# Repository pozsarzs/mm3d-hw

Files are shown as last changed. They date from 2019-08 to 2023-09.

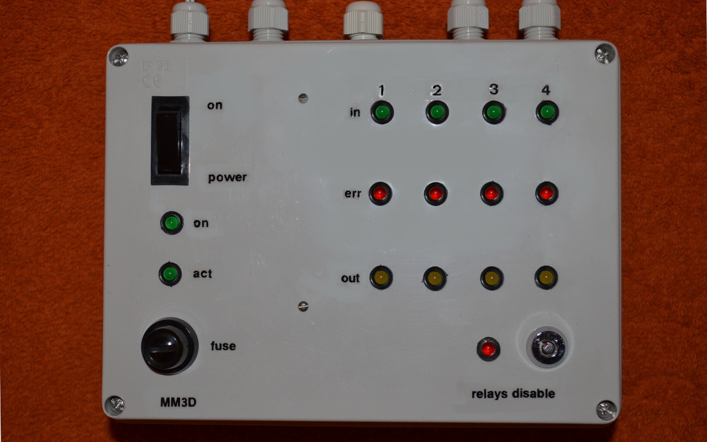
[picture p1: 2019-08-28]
pictures/mm3d.jpg

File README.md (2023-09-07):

**MM3D * Growing house controlling and remote monitoring device**  
Copyright (C) 2018-2020 Pozsár Zsolt <pozsarzs@gmail.com>  
Homepage: <http://www.pozsarzs.hu>  
GitHub: <https://github.com/pozsarzs/mm3d-hw>

**Documentation**

- version:             6.0
- language:            en, hu
- licence:             CC-BY-NC-4.0

**Hardware**

 - version:            v190203

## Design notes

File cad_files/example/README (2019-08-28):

Example of application
----------------------

Growing oyster mushroom in cellar
Cooperation with MM1A and MM2A analog controllers 

Inputs:
  in1:  (unused)
  in2:  water pressure (closed: good)
  in3:  growing hyphae/mushroom (closed: hyphae)
  in4:  (unused)

Error light:
  err1: bad relative humidity
  err2: bad water pressure
  err3: (unused)
  err4: bad temperature

Outputs:
  out1: humidifying (active in 5 s)
  out2: lighting
  out3: ventilation
  out4: heating

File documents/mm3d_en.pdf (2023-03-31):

## MM3D growing house controlling and monitoring unit

### Technical manual

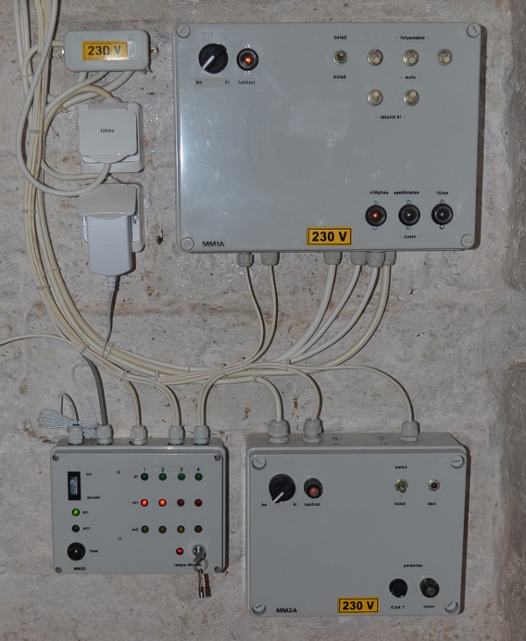
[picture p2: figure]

Hardware version: v190203
Software version: v0.8
User Manual version: v6.0
Issue date: 2022-03-13

## CC-BY-NC-4.0

(59/3)

Content

Titles: | MM3D growing house controlling and monitoring unit | Rev.: 190203 Pages: | 2/27
| Technical manual
Name: Pozsár Zsolt | Date: | 2022-03-13

## I. Hardware

Titles: | MM3D growing house controlling and monitoring unit | Rev.: 190203 Pages: | 3/27

The device is capable of measuring, controlling and monitoring the characteristics of a growing site.

### 1. Technical data

Supply voltage: | 5V DC (powered by 230 V AC/5 V DC adapter)
Supply current: | max. 2.5 A
Isolation class: | Class II.
Mechanical size: | 190 x 140 x 70 mm
IP protection: | IP 54
IK protection: | IK 03
Material of cover: | termoplaszt (ABS)
LAN: | Ethernet (RJ45)

Measured data:
value | range | resolution | accuration | note
temperature | -40...+80 °C | 0.1 °C | < ±0.5 °C | Length of sensor cable: max. 20 m
humidity | 0-100% RH | 0.1 % RH | ±2 % RH

Programmable in- and outputs:
sign | function | note
IN #1 | MMxA units in external control | TTL level inputs with pull-up resistor, theirs active state is „L”.
IN #2 | water pressure is good
IN #3 | mushroom/hyphae
IN #4 | MMxA units in automatic mode
OUT #1 | humidifying | NO/NC relay contact outputs. Load capacity: 250V 10A AC or 30V 10A DC. The operation of the relays can be switched off with a key switch, this status is indicated by a red LED.
OUT #2 | lighting
OUT #3 | ventilating
OUT #4 | heating

Programmable error lights:
sign | function | note
ERR #1 | bad humidity | Red LEDs on front panel.
ERR #2 | low water pressure
ERR #3 | control or sensor error
ERR #4 | bad temperature
Titles: | MM3D growing house controlling and monitoring unit | Rev.: 190203 Pages: | 4/27

### 2. Administration

Setting: | via SSH
Access data: | with web browser (via HTTP)

### 3. Description

The device is based on a Raspberry Pi 3 B + microcomputer with Raspbian operating system, which also includes software for operating the unit. No graphics system installed on it.

The device's four TTL-level inputs are equipped with pull-up resistors and have an active level of L. They can be used, for example, to check the position of air vents, doors and windows, check the functioning of the ventilation system (airflow sensor), the water pressure sensor, or the status of the motor or overcurrent protection devices with auxiliary contact.

The device has four relay contact outputs that are capable of switching to relatively high power (2.3 kW at 230V AC). The operation of the relays can be disabled by means of a front key switch; In all cases, external circuits must be provided with overcurrent protection.

There is no need to connect a keyboard or monitor to set up and operate the MM3D, and access to it is always done through SSH. Current status and measured data can be checked using a web browser.

### 4. Schematic and printed circuit drawings

The wiring diagram of the device is shown in Annex 1, PCB drawings are in Annex 3-7. You can download it as part of the complete documentation or in separate PS, PDF, SVG and KiCAD formats from the developer / manufacturer's website.

### 5. Terms of use

Hardware documentation can be modified and/or redistributed under the Creativ Commons 4.0 Attribution Non-Commercial (CC-BY-NC-4.0) License. You can read the full (English) text of the license online. (Refer to Chapter IV for references.)

Titles: | MM3D growing house controlling and monitoring unit | Rev.: 190203 Pages: | 5/27

### 6. Look of the device

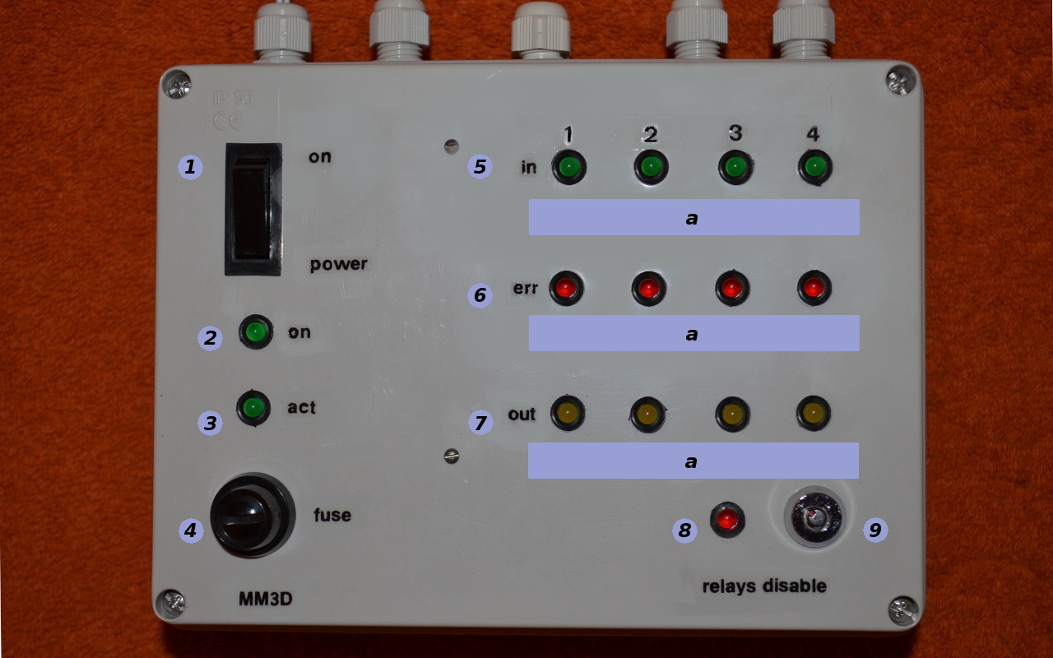
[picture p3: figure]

a) Manuals and connectors

1: supply voltage on/off switch 2: power on light (green LED)
3: ACT light (green LED)
4: fuse of supply voltage (2,5 A F)
5: IN #1-#4 input active status lights (green LED)
6: OUT #1-#4 output active status lights (yellow LED) 7: ERR #1-#4 error lights (red LED)
8: disable output relays light (red LED)
9: disable output relays switch

a: place for sticky labels

Titles: | MM3D growing house controlling and monitoring unit | Rev.: 190203 Pages: | 6/27

Figure 1: Front panel

b) Connector pinout

Input terminal (J1):
1: IN GND
2: IN #1
3: IN #2
4: IN #3
5: IN #4
6: -
7: -
8: S1 GND (external sensor GND) 9: S1 data (external sensor data) 10: S1 +5V (external sensor +5V) 11: +5 V in (power voltage input) 12: GND in (power voltage input)

Output terminal (J3):

1: NC1
2: COM1
3: NO1
4: NC2
5: COM2
6: NO2
7: NC3
8: COM3
9: NO3
10: NC4
11: COM4
12: NO4

Numbering on both connectors (terminal blocks) is in the installed position of device from top to bottom.

Titles: | MM3D growing house controlling and monitoring unit | Rev.: 190203 Pages: | 7/27

### 7. Downloadable documentation

The complete documentation of the hardware in the .tar.gz format compressed file can be downloaded from the manufacturer's website. (Refer to Chapter IV for references.)

Package's name: mm3d-hw-190203-6.0.tar.gz

Content:

mm3d-hw
│
├───cad_files | | KiCAD files
│ | ├───example | | | example of application
│ | │ | example_routing.pro | | | project file
│ | │ | example_routing.sch | | | schematic drawing
│ | │ | README | | | information
│ | │ | *.* | | | other files
│ | │
│ | └───mm3d | | | MM3D unit
│ | mm3d_base.pro | | base panel project file
│ | mm3d_base.kicad_pcb | | base printed circuit board
│ | mm3d_front.pro | | front panel project file
│ | mm3d_front.kicad_pcb | | front printed circuit board
│ | mm3d.pro | | schematic project file
│ | mm3d.sch | | schematic drawing
│ | *.* | | other files
│
├───documents | | documentation
│ | mm3d-hw_en.pdf | | Technical manual
│ | pcb_mm3d_base-comp.ps | | base panel component side
│ | pcb_mm3d_base-silk.ps | | base panel silkscreen
│ | pcb_mm3d_base-sold.ps | | base panel solder side
│ | pcb_mm3d_front-silk.ps | | front panel silkscreen
│ | pcb_mm3d_front-sold.ps | | front panel solder side
│ | sch_example.pdf | | example schematic drawing
│ | sch_mm3d.pdf | | MM3D schematic drawing
│
├───pictures | | pictures
│ | mm3d.jpg | | front panel
│ | pcb_mm3d_base-comp.svg | | base panel component side
│ | pcb_mm3d_base-silk.svg | | base panel silkscreen
│ | pcb_mm3d_base-sold.svg | | base panel solder side
│ | pcb_mm3d_front-silk.svg | | front panel silkscreen
│ | pcb_mm3d_front-sold.svg | | front panel solder side
│ | sch_example.svg | | example schematic drawing
│ | sch_mm3d.svg | | schematic drawing
│
├───LICENCE | terms of use
└───README.md | short description
Titles: | MM3D growing house controlling and monitoring unit | Rev.: 190203 Pages: | 8/27

## II. Software

Titles: | MM3D growing house controlling and monitoring unit | Rev.: 190203 Pages: | 9/27

### 1. General description

Operation of the device is provided by Python (control), Perl (data access) and Bash (utilities) scripts.

### 2. Prepare

Before installing the program, you must install Raspbian OS Lite on Raspberry Pi. Remember to change the default password for the user 'pi', configure the hostname and access to the local network. For easier remote access, use a permanent IP address or configure the IP address assignment on your router.

Prepare operation system:

pi@raspberry$ sudo apt-get update
pi@raspberry$ sudo apt-get upgrade
pi@raspberry$ sudo apt-get install git wget
pi@raspberry$ sudo echo "deb http://www.szerafingomba.hu/deb/ ./" >> /etc/apt/sources.list
pi@raspberry$ sudo wget -q -O - http://www.szerafingomba.hu/deb/KEY.gpg | apt-key add -
pi@raspberry$ sudo apt-get update
pi@raspberry$ mkdir $HOME/download

### 3. Download

Download from homepage:

pi@raspberry$ cd $HOME/download
pi@raspberry$ wget http://www.szerafingomba.hu/softwares/mm3d/mm3d-sw-0.8-armhf.tar.gz pi@raspberry$ tar -xzf mm3d-sw-0.8-armhf.tar.gz

Download new release from Github:

pi@raspberry$ cd $HOME/download
pi@raspberry$ git clone https://github.com/pozsarzs/mm3d-sw.git

### 4. Installation

pi@raspberry$ cd mm3d-sw
pi@raspberry$ ./prepare
pi@raspberry$ ./install

Install program from internet with package manager:

pi@raspberry$ sudo apt-get install mm3d-prepare pi@raspberry$ mm3d-prepare
pi@raspberry$ sudo apt-get install mm3d-sw mm3d-web mm3d-eec
Titles: | MM3D growing house controlling and monitoring unit | Rev.: 190203 Pages: | 10/27

The installed and created on runtime files (important files with info and target of symbolic links):

/
│
├───etc
│ | ├───cron.d
│ | │ | mm3d
│ | ├───init.d
│ | │ | mm3d.sh
│ | ├───rc0.d
│ | │ | K01mm3d.sh | » /etc/init.d/mm3d.sh
│ | ├───rc2.d
│ | │ | S01mm3d.sh | » /etc/init.d/mm3d.sh
│ | ├───rc3.d
│ | │ | S01mm3d.sh | » /etc/init.d/mm3d.sh
│ | │
│ | ├───rc4.d
│ | │ | S01mm3d.sh | » /etc/init.d/mm3d.sh
│ | ├───rc5.d
│ | │ | S01mm3d.sh | » /etc/init.d/mm3d.sh
│ | ├───rc6.d
│ | │ | K01mm3d.sh | » /etc/init.d/mm3d.sh
│ | ├───systemd
│ | │ | └───sytem
│ | │ | mm3d.service
│ | └───motd
├───usr
│ | ├───lib
│ | │ | | └───cgi
│ | │ | | | getdata.cgi
│ | │ | | | getenvirconf.cgi
│ | │ | | | getpage.cgi
│ | └───local
│ | | ├───bin
│ | | │ | | mm3d.py | daemon program
│ | │ | mm3d-creatediagrams | diagramok készítése
│ | │ | mm3d-editenvirconf | edit environment parameters
│ | │ | mm3d-editenvirconf.bin | edit environment parameters
│ | │ | mm3d-editmainconf | edit program configuration
│ | │ | mm3d-getsnapshots | kameraképek letöltése
│ | │ | mm3d-hwtest.py | hardver check
│ | │ | mm3d-maintainlog | log maintaining
│ | │ | mm3d-override | output manual control
│ | │ | mm3d-startdaemon | start daemon
│ | │ | mm3d-statusofdaemon | view status of daemon
│ | │ | mm3d-stopdaemon | stop daemon
│ | │ | mm3d-updatestartpage | update startpage
│ | │ | mm3d-viewlog | view log
│ | │ | mm3d-webpage | view own webpage
│ | ├───etc
│ | │ | └───mm3d
│ | │ | mm3d.ini | program configuration
│ | │ | envir.ini | environment parameters
│ | └───share
│ | | ├───doc
│ | | │ | └───mm3d
│ | | │ | AUTHORS | author
│ | | │ | ChangeLog | change log
│ | │ | control.txt | important variables
│ | │ | COPYING | licence
│ | │ | copyright | copyright information
│ | │ | gpioports.txt | GPIO port default pinout
Titles: | MM3D growing house controlling and monitoring unit | Rev.: 190203 Pages: | 11/27

│ | │ | INSTALL | installation instruction
│ | │ | README | description
│ | │ | VERSION | version
│ | ├───locale
│ | │ | └───??
│ | │ | mm3d.msg
│ | ├───man
│ | │ | └───man1 | manual pages
│ | │ | getdata.cgi.7.gz
│ | │ | getenvirconf.cgi.7.gz
│ | │ | getpage.cgi.7.gz
│ | │ | mm3d.py.8.gz
│ | │ | mm3d-creatediagrams.1.gz
│ | │ | mm3d-editenvirconf.1.gz
│ | │ | mm3d-editmainconf.1.gz
│ | │ | mm3d-getsnapshots.1.gz
│ | │ | mm3d-hwtest.py.1.gz
│ | │ | mm3d-maintainlog.1.gz
│ | │ | mm3d-override.1.gz
│ | │ | mm3d-startdaemon.1.gz
│ | │ | mm3d-statusofdaemon.1.gz
│ | │ | mm3d-stopdaemon.1.gz
│ | │ | mm3d-updatestartpage.1.gz
│ | │ | mm3d-viewlog.1.gz
│ | │ | mm3d-webpage.1.gz
│ | └───mm3d
│ | | footer_??.html
│ | | header_??.html
└───var
| ├───local
| │ | | ├───lib
| │ | | │ | | out1
| │ | | │ | | out2
| │ | | │ | | out3
| │ | | │ | | out4
| │ | | ├───lock
| │ | | │ | | mm3d.lock
| │ | | │
| │ | | └───log
| │ | | | mm3d.bak
| │ | | | mm3d.log
| │ | | | debug-*.log | | debug log
| ├───run
| │ | | mm3d.pid
| └───www
| | └───html
| | | ├───pics
│ | ants.jpg
│ | camera1.jpg
│ | camera2.jpg
│ | dark.png
│ | green.png
│ | humidity.png
│ | mm3d-creatediagrams.tmp
│ | red.png
│ | szerafin.ico
│ | temperature.png
│ | yellow.png
styles.css
index.html
szerafin.ico
Titles: | MM3D growing house controlling and monitoring unit | Rev.: 190203 Pages: | 12/27

It that is installed with the package manager is placed in the /usr directory instead of /usr/local.

### 3. Settings

Edit main settings:

mm3d@raspberry$ mm3d-editmainconf
The shellscript stops the service and opens the mm3d.ini file in the default editor. After saving the file, it refreshes the homepage and launches daemont. Content of configuration file:

; +----------------------------------------------------------------------------+
; | MM3D v0.6 * Growing house controlling and remote monitoring system | |
; | Copyright (C) 2018-2022 Pozsár Zsolt <pozsar.zsolt@szerafingomba.hu> | |
; | mm3d.ini | |
; | Main settings | |
; +----------------------------------------------------------------------------+

[user]
; User's data
usr_nam=User's name | ; user's name
usr_uid=00000000 | ; user's ID
usr_dt1=User's city | ; more data (eg. country)
usr_dt2=User's address | ; more data (eg. address)
usr_dt3=Growing house number | ; more data (eg. growing house)

[names]
; Name of error lights and ports
nam_err1=unnamed #1 | ; name of error lights
nam_err2=unnamed #2
nam_err3=unnamed #3
nam_err4=unnamed #4
nam_in1=unnamed #1 | ; name of inputs
nam_in2=unnamed #2
nam_in3=unnamed #3
nam_in4=unnamed #4
nam_out1=unnamed #1 | ; name of outputs
nam_out2=unnamed #2
nam_out3=unnamed #3
nam_out4=unnamed #4

[ports]
; GPIO port number of error lights and ports prt_act=24
prt_err1=14
prt_err2=15
prt_err3=18
prt_err4=23
prt_in1=2
prt_in2=3
prt_in3=4
prt_in4=17
prt_sens=11
prt_out1=27
prt_out2=22
prt_out3=10
prt_out4=9

[sensors]
; Type of temperature and humidity sensor ;sensor_type=AM2302
;sensor_type=DHT11
sensor_type=DHT22
Titles: | MM3D growing house controlling and monitoring unit | Rev.: 190203 Pages: | 13/27

[directories]
; Directories of program
dir_htm=/var/www/html/ | ; webserver's directory
dir_lck=/var/local/lock/ | ; lock file's directory
dir_log=/var/local/log/ | ; logfile's directory
dir_msg=/usr/local/share/locale/ | ; message files' directory
dir_shr=/usr/local/share/mm3d/ | ; other files' directory
dir_tmp=/var/tmp/ | ; place of temporary files
dir_var=/var/local/lib/mm3d/ | ; workfiles's directory
[openweathermap.org] | ;login data
api_key=00000000000000000000000000000000 base_url=http://api.openweathermap.org/data/2.5/weather?city_name=Tiszafoldvar
[ipcameras] | ; Show IP cameras' picture
cam_show=1
cam1_enable=0
cam1_jpglink=http://camera1-th01.lan/snapshot.cgi?user=username&pwd=password&count=0cam2_enable=0
cam2_jpglink=http://camera2-th01.lan/snapshot.cgi?user=username&pwd=password&count=0

[others]
; Language of webpage
lng=en
;lng=...
; Storing time of log
day_log=7
; Enable/disable verbose debug log
dbg_log=0
; Number of log lines on web interface
web_lines=30 | ; Showed log lines

Set growing environment parameters:

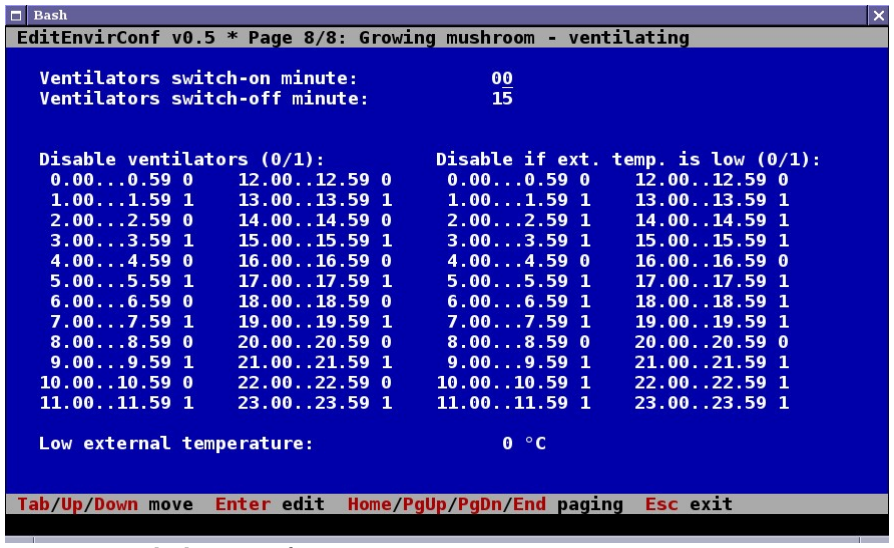
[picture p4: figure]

mm3d@raspberry$ mm3d-editenvirconf

Titles: | MM3D growing house controlling and monitoring unit | Rev.: 190203 Pages: | 14/27

Figure 2: mm3d-editenvirconf

The shell program starts the setup program and then resumes the service after saving and exiting.

### 6. Using the device

The device works automatically after installation and does not require human intervention. Checking and configuring your operation is only possible remotely via a network.

The device can be configured via SSH, the environmental characteristics can be set via SSH or with XMMEEC program. In the second case, a key-based login is required.

The set environment characteristic, the current status and the measured data can be checked with a web browser or MM3DRead program. Many data can be queried over HTTP without a browser. See getdata.cgi.7.gz manual page for details.

### 7. Terms of use

This program is free software: you can redistribute it and/or modify it under the terms of the European Union Public License 1.1 version.

This program is distributed in the hope that it will be useful, but WITHOUT ANY WARRANTY; without even the implied warranty of MERCHANTABILITY or FITNESS FOR A PARTICULAR PURPOSE.

You can read the full text of the license online. (Refer to Chapter IV for references.)

### 8. Downloadable software package

The package can be downloaded from the manufacturer's website in a .tar.gz compressed file. (Refer to Chapter IV for references.) Name of current package: mm3d-sw-0.8-armhf.tar.gz

Titles: | MM3D growing house controlling and monitoring unit | Rev.: 190203 Pages: | 15/27

Content of package:

mm3d-sw
│
├───binary | binary files
│
├───documents | documentation
│
├───manuals | manual pages
│
├───messages | translated webpage text
│
├───packaging | files for make deb packages
│
├───programs | programs (Python)
│
├───scripts | programs (Bash)
│
├───settings | settings
│
├───source | source code
│
├───webpage | | components of webpage
│
├───install | installer script
├───prepare | script for prepare OS
├───uninstall | uninstaller script
├───LICENCE | terms of use
└───README.md | short description
Titles: | MM3D growing house controlling and monitoring unit | Rev.: 190203 Pages: | 16/27

## III. Related links

Titles: | MM3D growing house controlling and monitoring unit | Rev.: 190203 Pages: | 17/27

### 1. Hardware

Full documentation | http://www.szerafingomba.hu/equipments/mm3d/mm3d-hw-190203-6.0.tar.gz
Github | https://github.com/pozsarzs/mm3d-hw.git
Technical manual | http://www.szerafingomba.hu/equipments/mm3d/technical-manual-190203-6.0-en.pdf

Schematic drawings:
Example (PDF) | http://www.szerafingomba.hu/equipments/mm3d/sch_mm3d-example.pdf
MM3D (PDF) | http://www.szerafingomba.hu/equipments/mm3d/sch_mm3d.pdf

Printed circuit boards:
MM3D base | http://www.szerafingomba.hu/equipments/mm3d/pcb_mm3d-1.zip
MM3D front | http://www.szerafingomba.hu/equipments/mm3d/pcb_mm3d-2.zip

### 2. Software

Software package | http://www.szerafingomba.hu/softwares/mm3d/mm3d-sw-0.8.1-armhf.tar.gz
Github | http://github.com/pozsarzs/mm3d-sw.git

### 3. Terms of use

CC-BY-NC-4.0 | https://creativecommons.org/licenses/by-nc/4.0/legalcode
CC-BY-NC-4.0 | https://creativecommons.org/licenses/by-nc/4.0/
EUPL v1.2 | https://eupl.eu/1.2/en/

### 4. Developer and manufacturer

Homepage | https://www.szerafingomba.hu
E-mail | info@szerafingomba.hu
Titles: | MM3D growing house controlling and monitoring unit | Rev.: 190203 Pages: | 18/27

## IV. Annexes

Titles: | MM3D growing house controlling and monitoring unit | Rev.: 190203 Pages: | 19/27

### 1. Schematic drawings

1. Schematic of MM3D
2. Example of application

### 2. Printed circuit boards

3. Base panel component side
4. Base panel solder side
5. Base panel silkscreen
6. Front panel component side
7. Front panel silkscreen
Titles: | MM3D growing house controlling and monitoring unit | Rev.: 190203 Pages: | 20/27

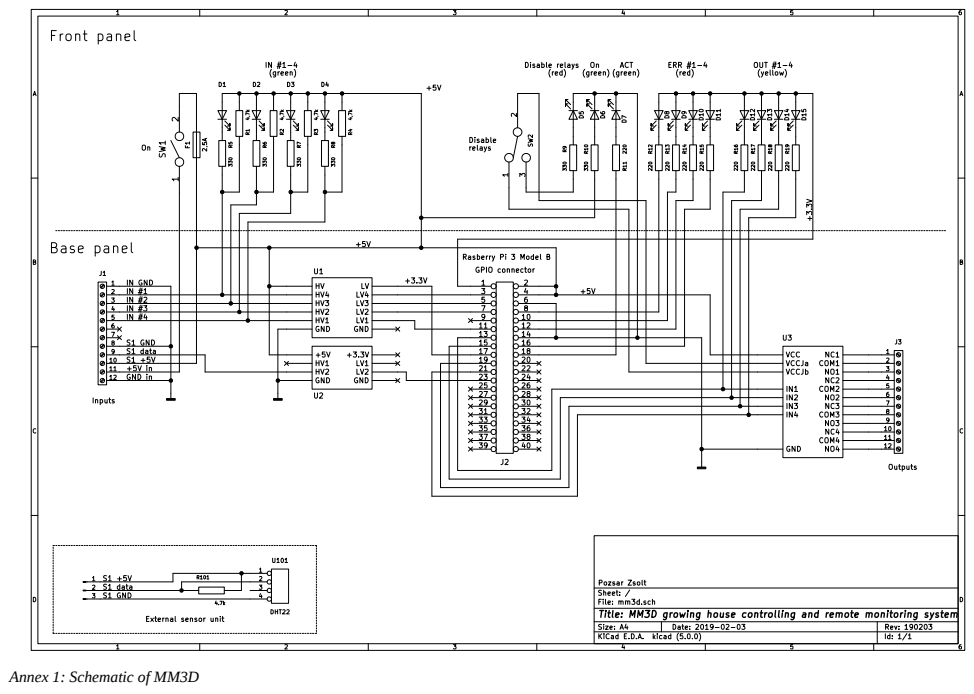
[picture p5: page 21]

Annex 1: Schematic of MM3D

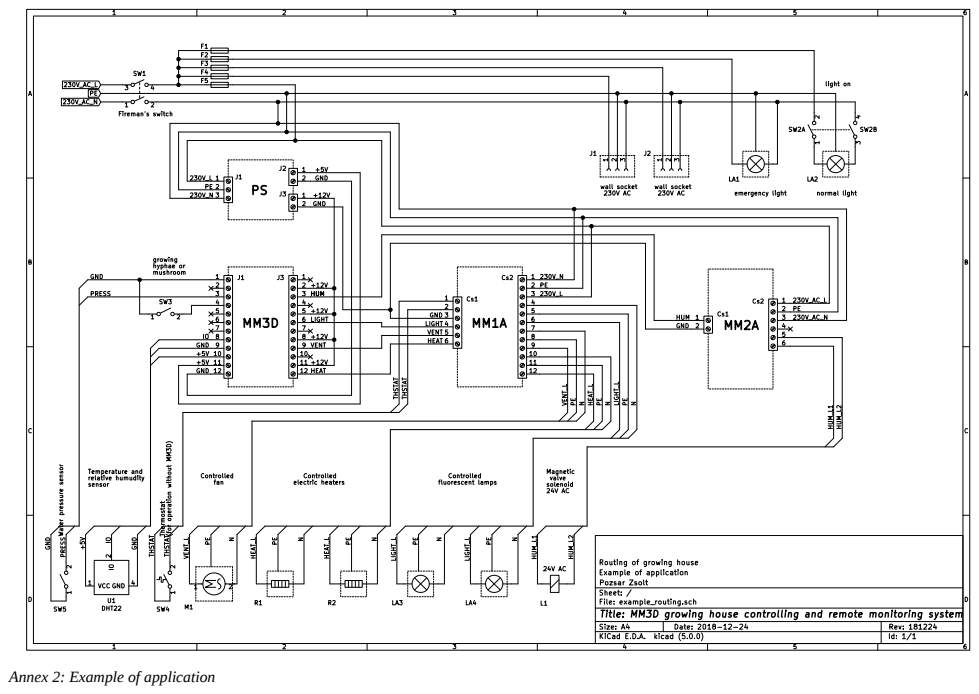
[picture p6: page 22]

Annex 2: Example of application

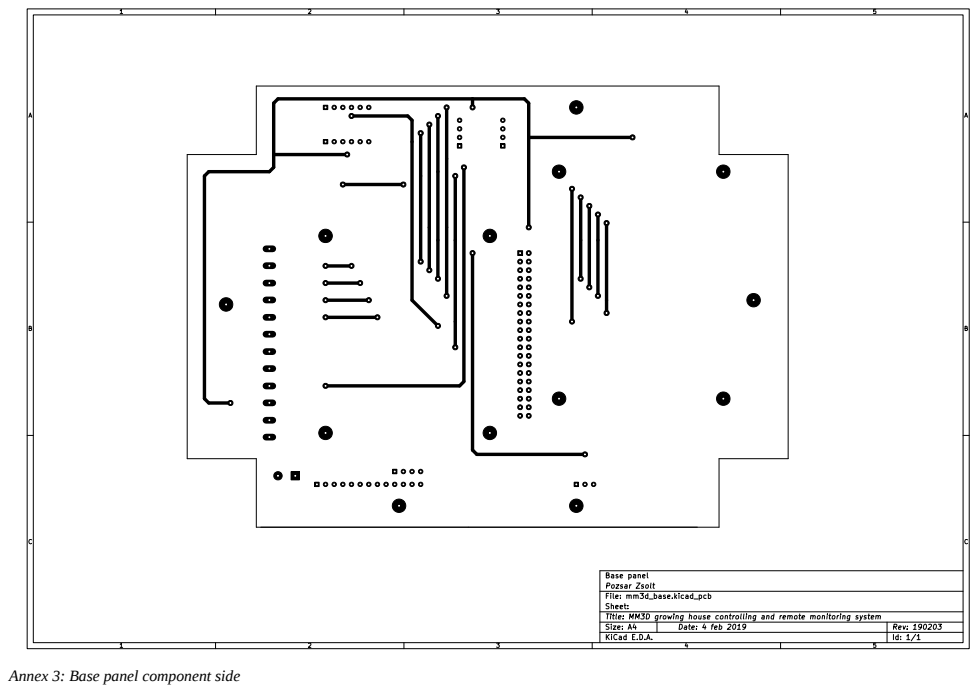
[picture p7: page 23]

Annex 3: Base panel component side

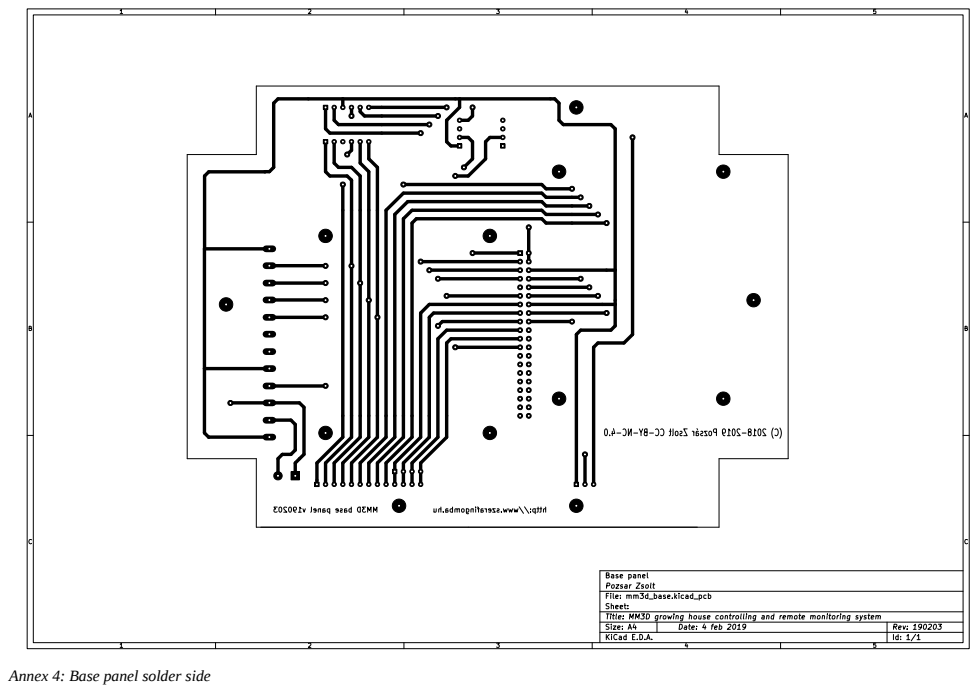
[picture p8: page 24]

Annex 4: Base panel solder side

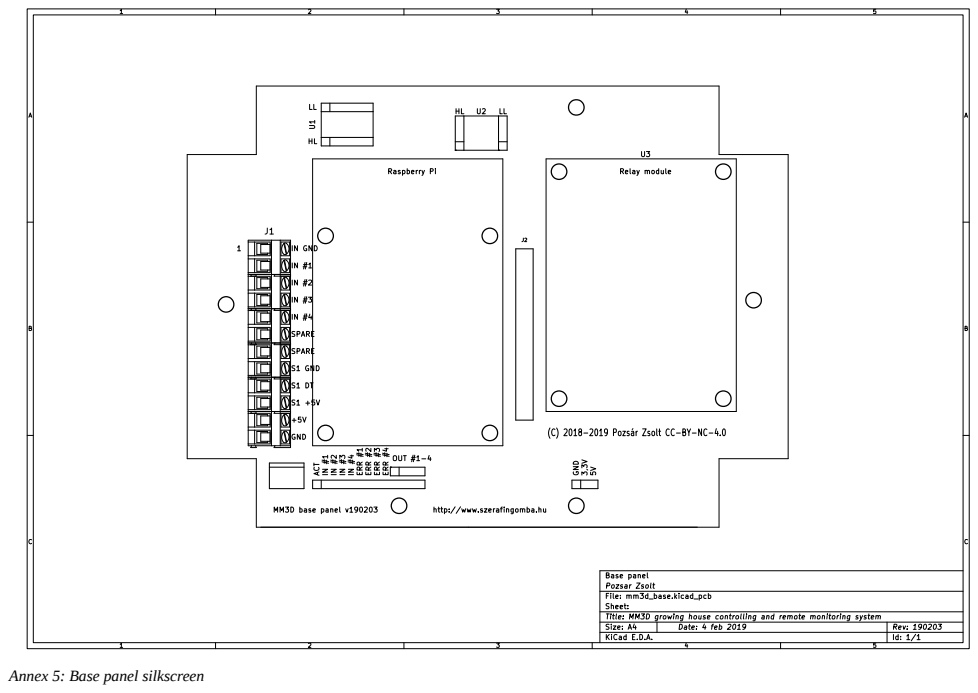
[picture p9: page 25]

Annex 5: Base panel silkscreen

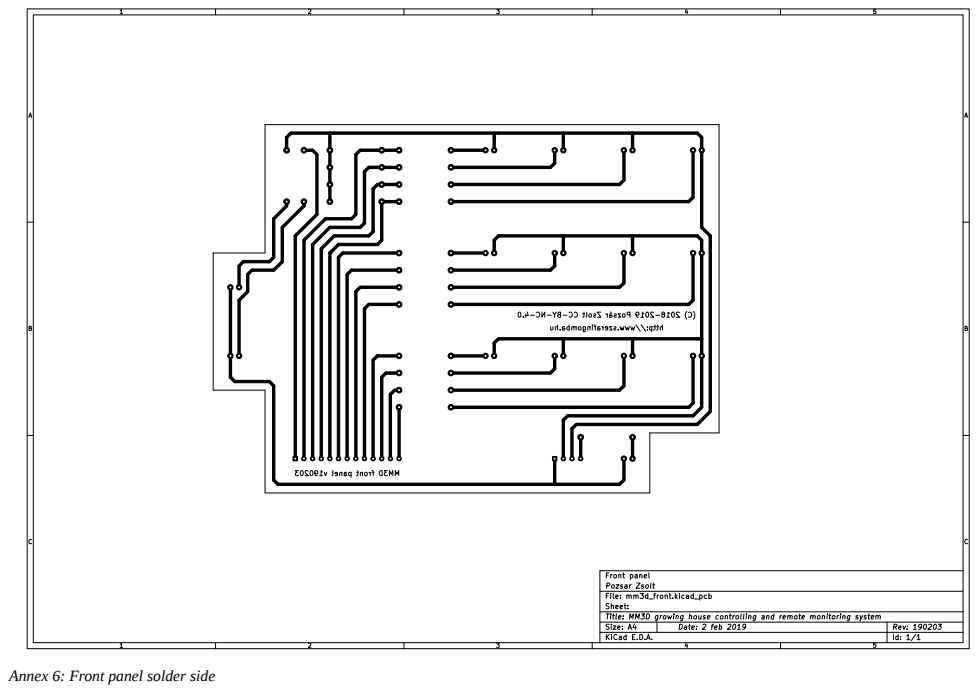
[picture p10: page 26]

Annex 6: Front panel solder side

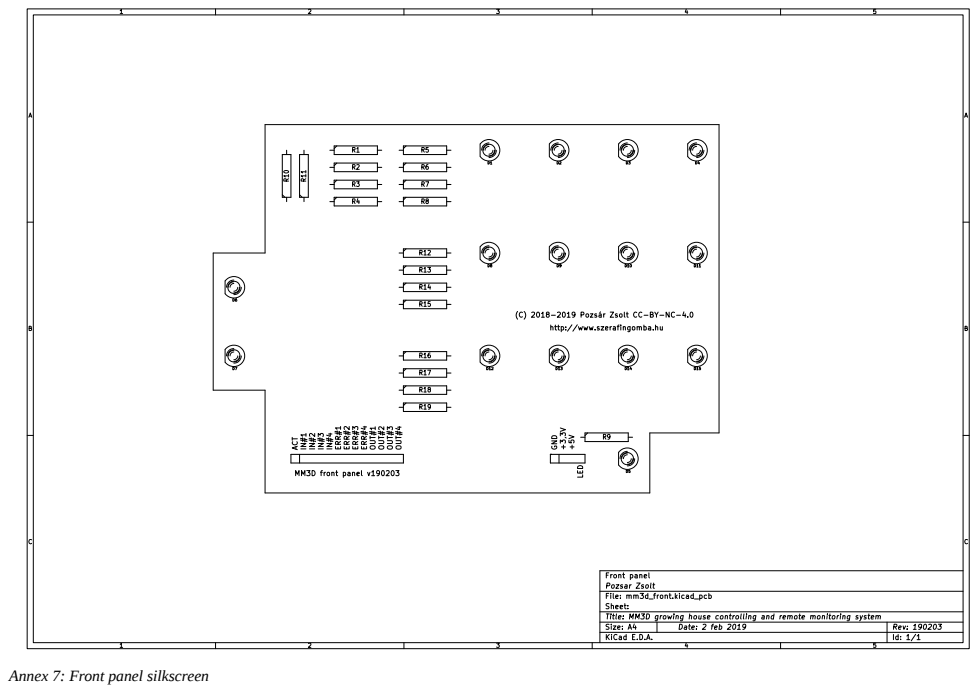
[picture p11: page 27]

Annex 7: Front panel silkscreen

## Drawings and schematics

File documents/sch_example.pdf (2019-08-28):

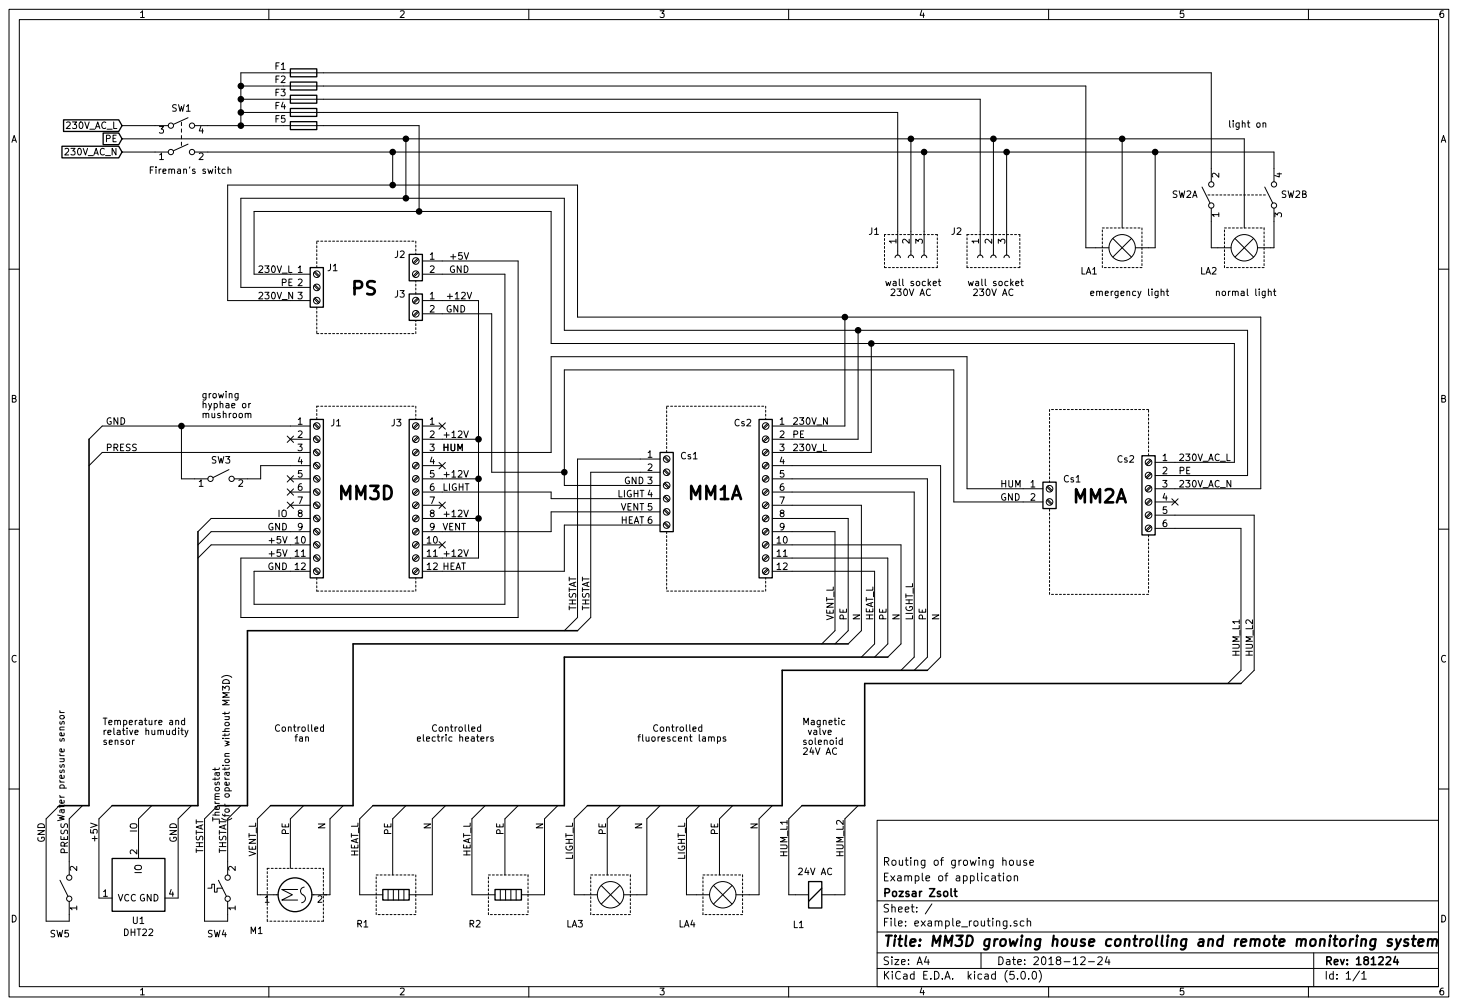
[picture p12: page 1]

fan Thermostat (for operation without MM3D) Temperature and

sensor Water pressure sensor

Routing of growing house
File: example_routing.sch Sheet: / Pozsar Zsolt Example of application

Id: 1/1 Title: MM3D growing house controlling and remote monitoring system

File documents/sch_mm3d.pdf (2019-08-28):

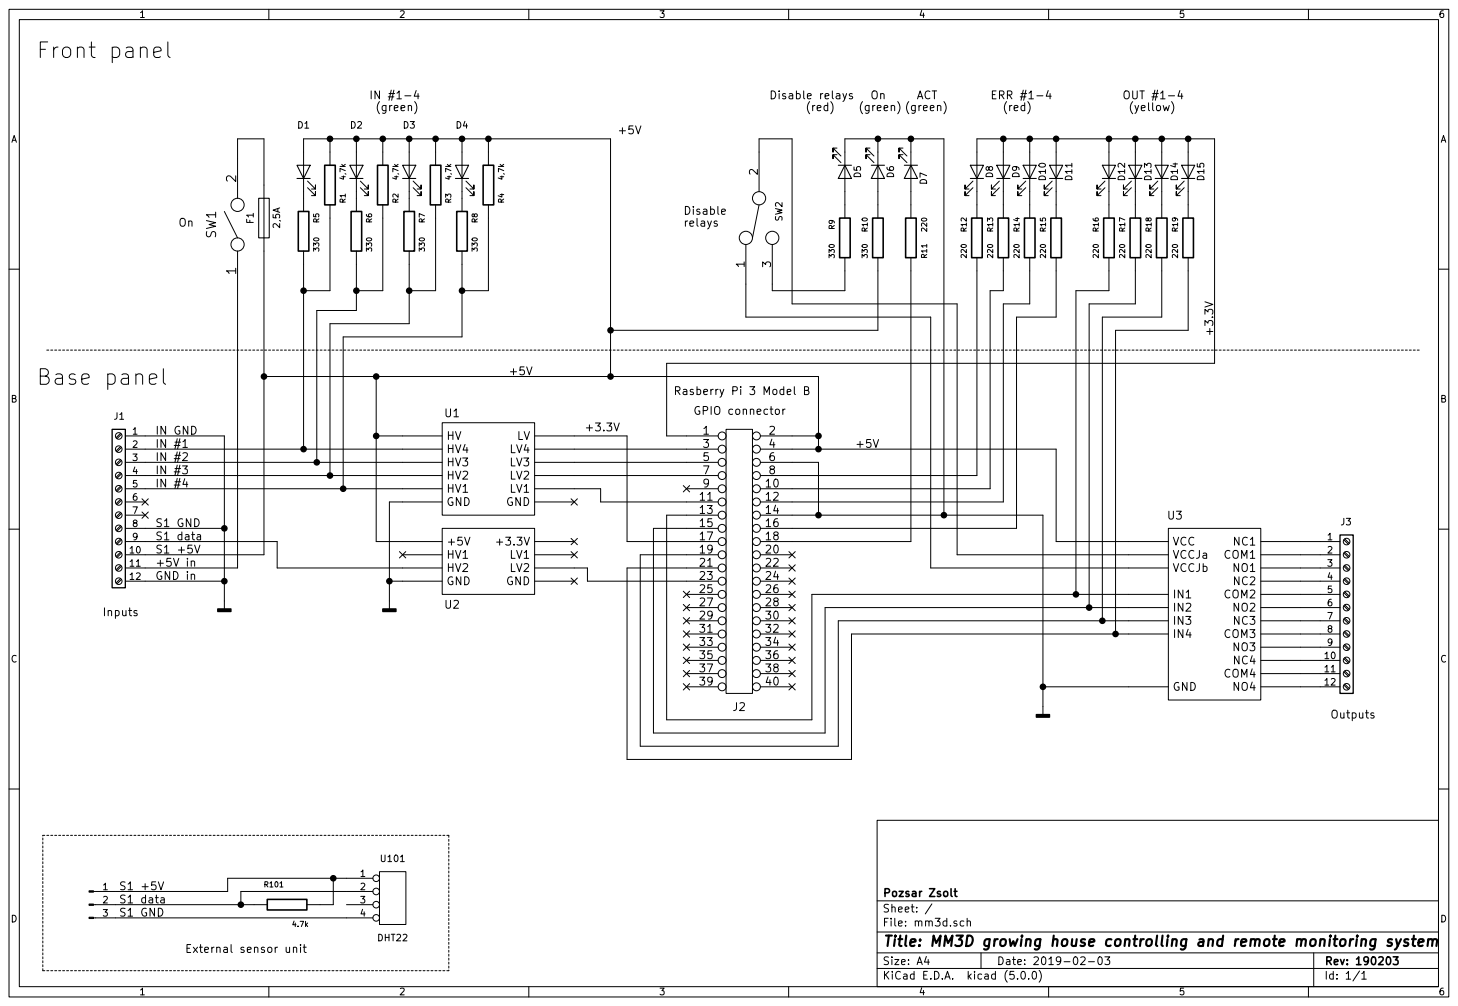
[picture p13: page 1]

3 | IN #2
4 | IN #3

Id: 1/1 Title: MM3D growing house controlling and remote monitoring system
